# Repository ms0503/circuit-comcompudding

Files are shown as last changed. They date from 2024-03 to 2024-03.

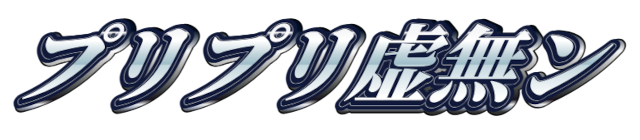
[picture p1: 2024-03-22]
kaibunsho.png

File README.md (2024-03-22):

ComComPudding
=============

ComComPuddingは「通信」を主軸に設計された汎用基板です。
MCUはSTM32F405RGT6を採用しコンパクトながら素早く処理することができます。

# 使用IC
## MCP2542WFD
高速通信可能なCANトランシーバです。
詳細は[データシート](https://ww1.microchip.com/downloads/aemDocuments/documents/APID/ProductDocuments/DataSheets/MCP2542FD-MCP2542WFD-4WFD-Data-Sheet-DS20005514C.pdf)
をご覧下さい。

## STM32F405RGT6
メインの処理を担当するMCUです。
詳細は[データシート](https://www.st.com/resource/en/datasheet/stm32f405rg.pdf)
及び[リファレンスマニュアル](https://www.stmcu.jp/download/?dlid=51544_jp)
をご覧下さい。

# インターフェース
## CAN
CAN(Control Area Network)向けのポートが1系統、2つ搭載されており、CANへのアクセス、
5V電源の供給を行うことが出来ます。
### 信号レベル
- マイコン側：3.3V
- 端子側：5V

### マイコンピン
TX：PA11
RX：PA12

## I²C
I²C(Inter-Intergrated Circuit)向けのポートが1系統、1つ搭載されており、I²Cへのアクセス、
5V電源の供給を行うことが出来ます。
### 信号レベル
3.3V
### マイコンピン
I2C1\_SCL：PB6
I2C1\_SDA：PB7

## LED
基板表面に実装された4つのLEDで簡易的な状態表示を行うことが出来ます。
### 信号レベル
3.3V
### マイコンピン
LED1：PB12
LED2：PB13
LED3：PB14
LED4：PB15

## SPI
SPI(Serial Peripheral Interface)向けのポートが2系統、3つ搭載されており、SlaveとしてのMasterとの通信、
MasterとしてのSlave(最大2台まで)との通信、5V電源の供給を行うことが出来ます。  
SPI1をSlave動作、SPI2をMaster動作とすることを想定しています。
### 信号レベル
3.3V
### マイコンピン
SPI1\_SCK：PA5
SPI1\_MISO：PA6
SPI1\_MOSI：PA7
SPI1\_SS：PA4
SPI2\_SCK：PB10
SPI2\_MISO：PC2
SPI2\_MOSI：PC3
SPI2\_SS\_1：PC0
SPI2\_SS\_2：PC1

## U(S)ART
USART(Universal Synchronous-Asynchronous Receiver and Transmitter)向けのポートが4つ、
UART(Universal Asynchronous Receiver and Transmitter)向けのポートが2つ、計6つ搭載されており、
U(S)ARTデバイスとの通信、5V電源の供給を行うことが出来ます。
### 信号レベル
3.3V
### マイコンピン
USART1\_TX：PA9
USART1\_RX：PA10
USART2\_TX：PA2
USART2\_RX：PA3
USART3\_TX：PC10
USART3\_RX：PB11
UART4\_TX：PA0
UART4\_RX：PA1
UART5\_TX：PC12
UART5\_RX：PD2
USART6\_TX：PC6
USART6\_RX：PC7

# ライブラリ
この基板は一部のシンボル・フットプリントに[kicad-mecha](https://github.com/ms0503/kicad-mecha.git)を使用しています。
別途インポートした上でご利用下さい。

# 設計者
Sora Tonami <[ms0503@outlook.com](mailto:ms0503@outlook.com)>

# ライセンス
この基板のデータは[MITライセンス](LICENSE.md)の下に公開されます。ご自由に改変・再配布して頂いて構いません。

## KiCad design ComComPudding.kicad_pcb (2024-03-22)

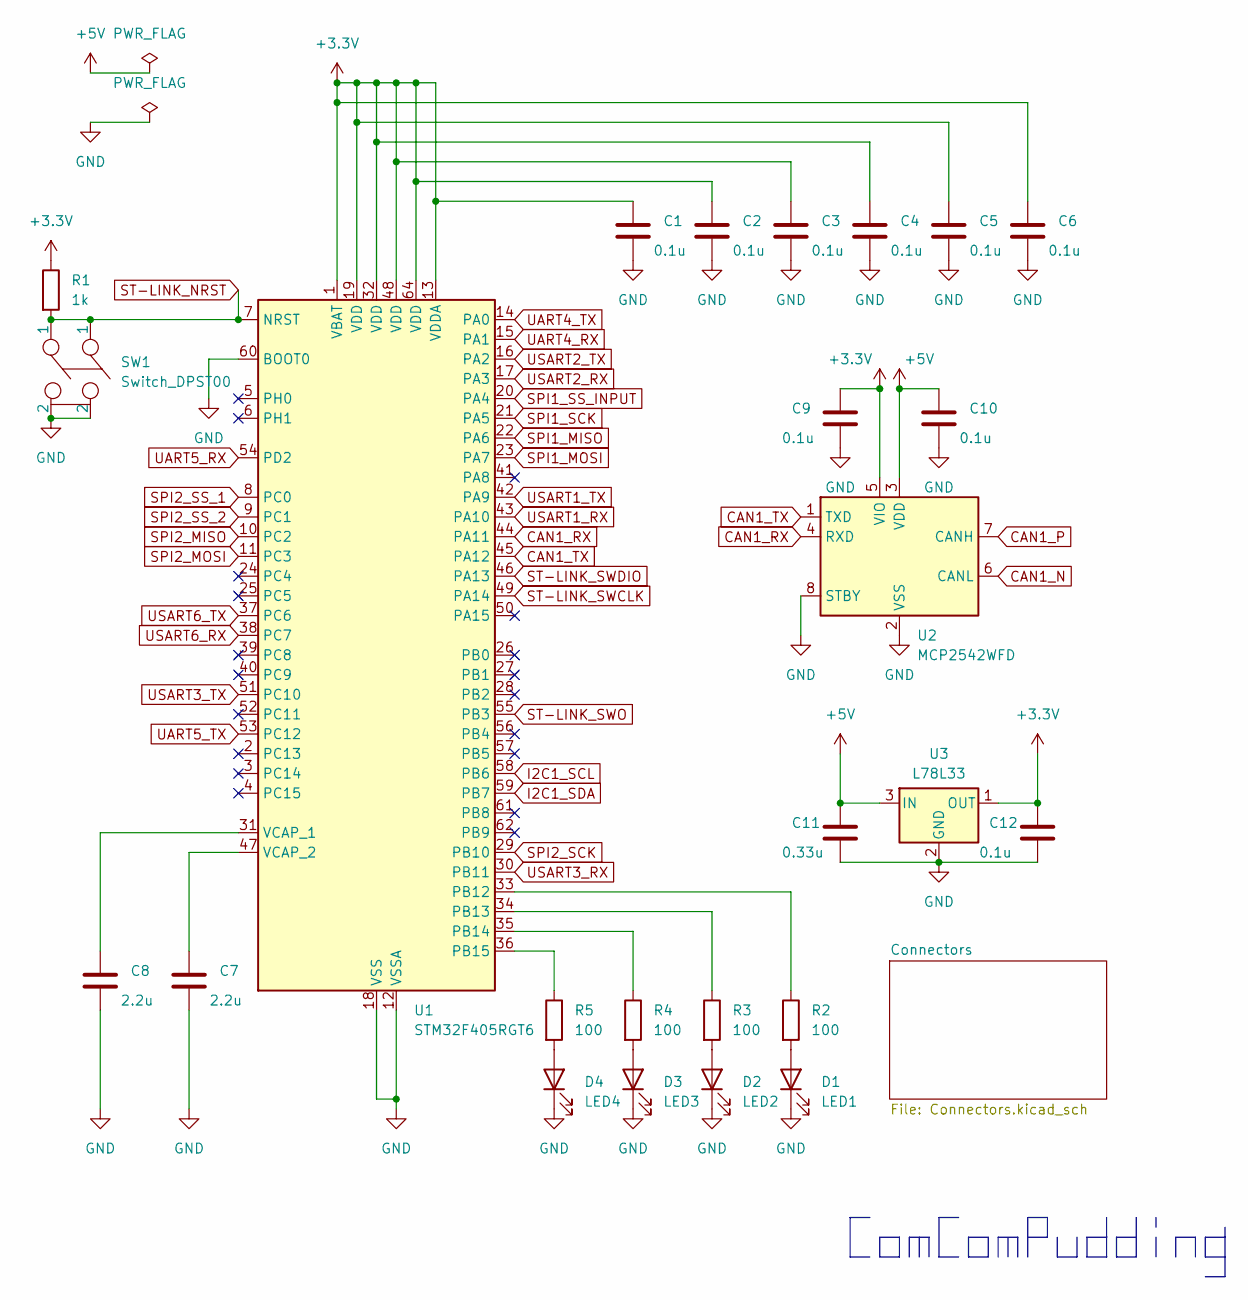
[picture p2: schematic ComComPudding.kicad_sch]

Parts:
C1, C2, C3, C4, C5, C6, C9, C10, C12: 0.1u; C_0603_1608Metric
C7, C8: 2.2u; C_0603_1608Metric
C11: 0.33u; C_0603_1608Metric
D1: LED1; LED_0805_2012Metric
D2: LED2; LED_0805_2012Metric
D3: LED3; LED_0805_2012Metric
D4: LED4; LED_0805_2012Metric
R1: 1k; R_0603_1608Metric
R2, R3, R4, R5: 100; R_0603_1608Metric
SW1: Switch_DPST00; SW_Tactile_Straight_KSA0Axx1LFTR
U1: STM32F405RGT6; LQFP-64_10x10mm_P0.5mm
U2: MCP2542WFD; DFN-8-1EP_3x3mm_P0.65mm_EP1.55x2.4mm
U3: L78L33; SOT-89-3

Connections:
+3.3V: C1.1, C2.1, C3.1, C4.1, C5.1, C6.1, C9.1, C12.1, R1.1, U1.1 (VBAT), U1.13 (VDDA), U1.19 (VDD), U1.32 (VDD), U1.48 (VDD), U1.64 (VDD), U2.5 (VIO), U3.1 (OUT); also elsewhere on the board
+5V: C10.1, C11.1, U2.3 (VDD), U3.3 (IN); also elsewhere on the board
CAN1_N: U2.6 (CANL); also elsewhere on the board
CAN1_P: U2.7 (CANH); also elsewhere on the board
CAN1_RX: U1.44 (PA11), U2.4 (RXD)
CAN1_TX: U1.45 (PA12), U2.1 (TXD)
GND: C1.2, C2.2, C3.2, C4.2, C5.2, C6.2, C7.2, C8.2, C9.2, C10.2, C11.2, C12.2, D1.1 (K), D2.1 (K), D3.1 (K), D4.1 (K), SW1.2, U1.12 (VSSA), U1.18 (VSS), U1.60 (BOOT0), U1.63 (VSS), U2.2 (VSS), U2.8 (STBY), U2.9 (VSS), U3.2 (GND); also elsewhere on the board
I2C1_SCL: U1.58 (PB6); also elsewhere on the board
I2C1_SDA: U1.59 (PB7); also elsewhere on the board
unnamed: D1.2 (A), R2.2
unnamed: D2.2 (A), R3.2
unnamed: D3.2 (A), R4.2
unnamed: D4.2 (A), R5.2
unnamed: R2.1, U1.33 (PB12)
unnamed: R3.1, U1.34 (PB13)
unnamed: R4.1, U1.35 (PB14)
unnamed: R5.1, U1.36 (PB15)
unnamed: C8.1, U1.31 (VCAP_1)
unnamed: C7.1, U1.47 (VCAP_2)
SPI1_MISO: U1.22 (PA6); also elsewhere on the board
SPI1_MOSI: U1.23 (PA7); also elsewhere on the board
SPI1_SCK: U1.21 (PA5); also elsewhere on the board
SPI1_SS_INPUT: U1.20 (PA4); also elsewhere on the board
SPI2_MISO: U1.10 (PC2); also elsewhere on the board
SPI2_MOSI: U1.11 (PC3); also elsewhere on the board
SPI2_SCK: U1.29 (PB10); also elsewhere on the board
SPI2_SS_1: U1.8 (PC0); also elsewhere on the board
SPI2_SS_2: U1.9 (PC1); also elsewhere on the board
ST-LINK_NRST: R1.2, SW1.1, U1.7 (NRST); also elsewhere on the board
ST-LINK_SWCLK: U1.49 (PA14); also elsewhere on the board
ST-LINK_SWDIO: U1.46 (PA13); also elsewhere on the board
ST-LINK_SWO: U1.55 (PB3); also elsewhere on the board
UART4_RX: U1.15 (PA1); also elsewhere on the board
UART4_TX: U1.14 (PA0); also elsewhere on the board
UART5_RX: U1.54 (PD2); also elsewhere on the board
UART5_TX: U1.53 (PC12); also elsewhere on the board
USART1_RX: U1.43 (PA10); also elsewhere on the board
USART1_TX: U1.42 (PA9); also elsewhere on the board
USART2_RX: U1.17 (PA3); also elsewhere on the board
USART2_TX: U1.16 (PA2); also elsewhere on the board
USART3_RX: U1.30 (PB11); also elsewhere on the board
USART3_TX: U1.51 (PC10); also elsewhere on the board
USART6_RX: U1.38 (PC7); also elsewhere on the board
USART6_TX: U1.37 (PC6); also elsewhere on the board

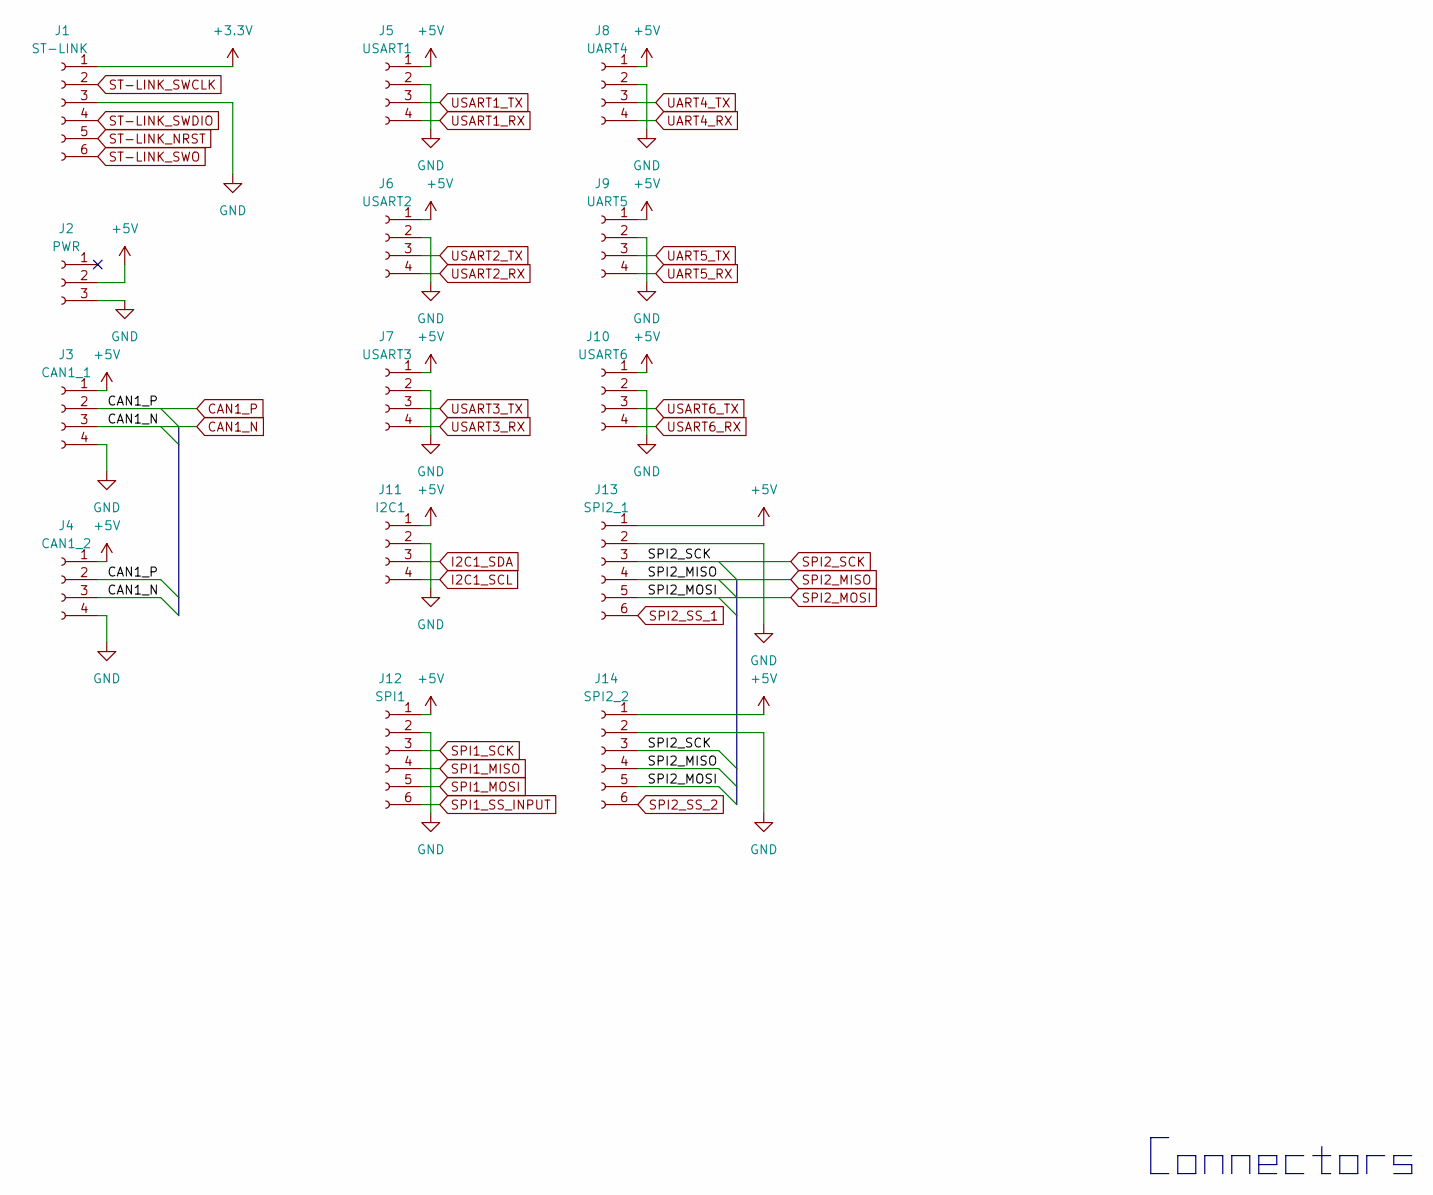
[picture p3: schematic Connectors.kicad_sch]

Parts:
J1: ST-LINK; ZH_6pin_Straight
J2: PWR; JST_XH_B3B-XH-A_1x03_P2.50mm_Vertical
J3: CAN1_1; XA_4pin_Straight
J4: CAN1_2; XA_4pin_Straight
J5: USART1; DF1B-4P-2.5DSA
J6: USART2; DF1B-4P-2.5DSA
J7: USART3; DF1B-4P-2.5DSA
J8: UART4; DF1B-4P-2.5DSA
J9: UART5; DF1B-4P-2.5DSA
J10: USART6; DF1B-4P-2.5DSA
J11: I2C1; XA_4pin_Straight
J12: SPI1; XH_Connector_6pin
J13: SPI2_1; XH_Connector_6pin
J14: SPI2_2; XH_Connector_6pin

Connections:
+3.3V: J1.1; also elsewhere on the board
+5V: J2.2, J3.1, J4.1, J5.1, J6.1, J7.1, J8.1, J9.1, J10.1, J11.1, J12.1, J13.1, J14.1; also elsewhere on the board
CAN1_N: J3.3, J4.3; also elsewhere on the board
CAN1_P: J3.2, J4.2; also elsewhere on the board
GND: J1.3, J2.3, J3.4, J4.4, J5.2, J6.2, J7.2, J8.2, J9.2, J10.2, J11.2, J12.2, J13.2, J14.2; also elsewhere on the board
I2C1_SCL: J11.4; also elsewhere on the board
I2C1_SDA: J11.3; also elsewhere on the board
SPI1_MISO: J12.4; also elsewhere on the board
SPI1_MOSI: J12.5; also elsewhere on the board
SPI1_SCK: J12.3; also elsewhere on the board
SPI1_SS_INPUT: J12.6; also elsewhere on the board
SPI2_MISO: J13.4, J14.4; also elsewhere on the board
SPI2_MOSI: J13.5, J14.5; also elsewhere on the board
SPI2_SCK: J13.3, J14.3; also elsewhere on the board
SPI2_SS_1: J13.6; also elsewhere on the board
SPI2_SS_2: J14.6; also elsewhere on the board
ST-LINK_NRST: J1.5; also elsewhere on the board
ST-LINK_SWCLK: J1.2; also elsewhere on the board
ST-LINK_SWDIO: J1.4; also elsewhere on the board
ST-LINK_SWO: J1.6; also elsewhere on the board
UART4_RX: J8.4; also elsewhere on the board
UART4_TX: J8.3; also elsewhere on the board
UART5_RX: J9.4; also elsewhere on the board
UART5_TX: J9.3; also elsewhere on the board
USART1_RX: J5.4; also elsewhere on the board
USART1_TX: J5.3; also elsewhere on the board
USART2_RX: J6.4; also elsewhere on the board
USART2_TX: J6.3; also elsewhere on the board
USART3_RX: J7.4; also elsewhere on the board
USART3_TX: J7.3; also elsewhere on the board
USART6_RX: J10.4; also elsewhere on the board
USART6_TX: J10.3; also elsewhere on the board

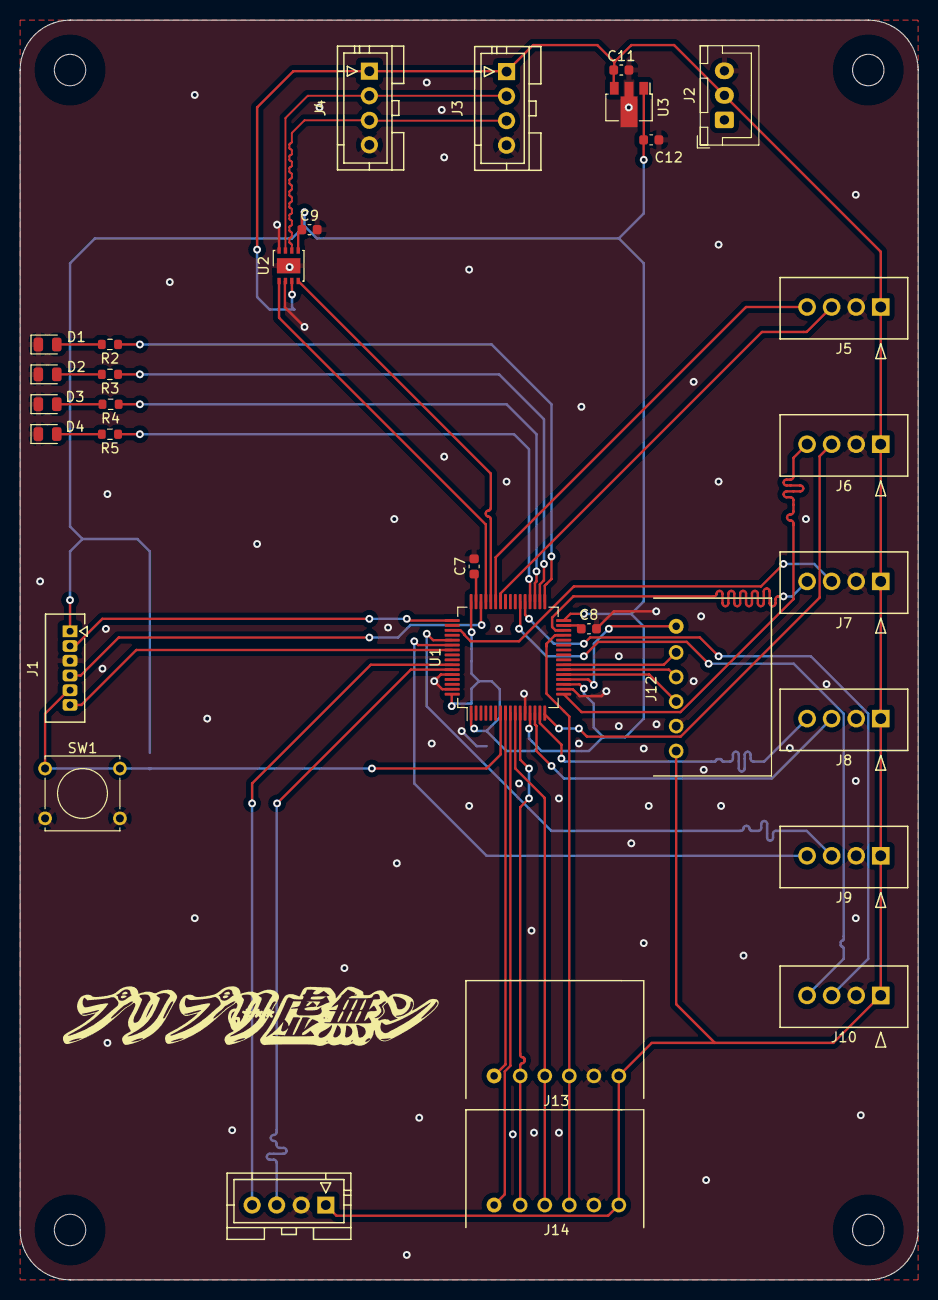
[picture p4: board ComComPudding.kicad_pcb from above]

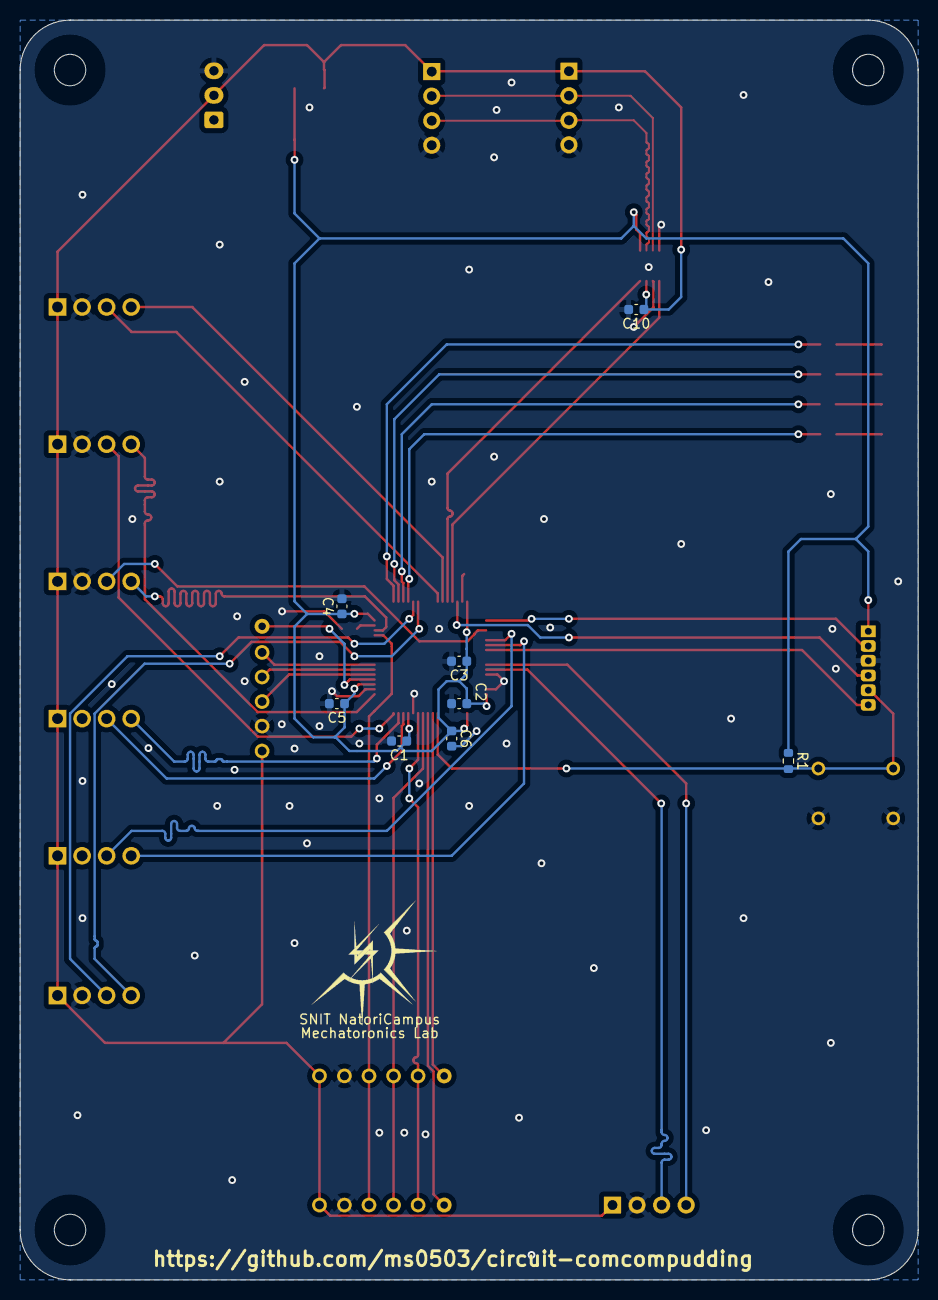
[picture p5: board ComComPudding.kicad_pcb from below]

Board: 2 copper layers, 91.4 x 128.3 mm, 43 parts (8 on the bottom side), 44 nets.

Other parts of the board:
 : holeφ3.2
 #2,  #3,  #4: holeφ3.2
